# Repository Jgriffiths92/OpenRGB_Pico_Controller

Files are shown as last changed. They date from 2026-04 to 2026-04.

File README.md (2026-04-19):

# RGB Pico SATA Controller

This project is an open-source RGB controller designed to interface with 12v RGB devices using a Raspberry Pi Pico microcontroller. It features custom firmware and hardware, supporting the OpenRGB protocol for seamless integration with popular RGB control software.

RGB Pico SATA Controller is an open-source hardware and firmware project that enables control of standard (dumb) 12V RGB devices (such as common 12V RGB LED strips and PC lighting) using a Raspberry Pi Pico microcontroller. The controller connects via a SATA power connector for easy integration into PC builds and communicates with the OpenRGB desktop application using the OpenRGB protocol. This allows users to synchronize and customize their RGB lighting through a unified software interface.

The project includes:
- Custom PCB design (KiCad)
- Firmware written in C for the Raspberry Pi Pico
- Support for OpenRGB protocol for cross-platform compatibility

## Features
- Control standard (dumb) 12V RGB LEDs (common anode, 4-pin) via SATA power connector
- Seamless integration with OpenRGB software
- USB HID communication for low-latency control
- Open-source hardware (schematic, PCB, Gerber files)
- Easy-to-build firmware with CMake
- Designed for PC modding and custom lighting projects

## Folder Structure
- `Firmware/` — Source code for the Pico firmware (C, CMake)
- `Gerber/` — PCB manufacturing files for the controller
- `RGB_PICO_SATA_CONTROLLER.kicad_*` — KiCad schematic and PCB design files

## Hardware Overview
The hardware consists of a custom PCB designed in KiCad, featuring:
- Raspberry Pi Pico (RP2040) microcontroller
- SATA power input for 12V supply
- MOSFET drivers for switching 12V power to each RGB channel
- 4-pin connectors for standard 12V RGB LED strips (common anode)

All design files are provided in the repository (`.kicad_sch`, `.kicad_pcb`, and Gerber files).
## Getting Started
### Hardware
1. Open the KiCad project files (`RGB_PICO_SATA_CONTROLLER.kicad_sch`, `.kicad_pcb`) to view or modify the schematic and PCB layout.
2. Use the Gerber files in the `Gerber/` directory to order PCBs from your preferred manufacturer.
3. Assemble the board using the schematic and bill of materials (BOM).
4. Solder the Raspberry Pi Pico and connectors as indicated.

### Firmware
1. Install the Raspberry Pi Pico SDK and required toolchain (CMake, GCC, etc.).
2. Clone this repository and navigate to the `Firmware/` directory.
3. Build the firmware:
   ```sh
   mkdir build
   cd build
   cmake ..
   make
   ```
4. Connect your Pico in BOOTSEL mode and copy the generated `.uf2` file to the Pico's USB drive.

### Software (OpenRGB)
1. Download and install the OpenRGB application from [openrgb.org](https://openrgb.org/).
2. Connect the RGB Pico SATA Controller to your PC via USB.
3. Open OpenRGB and the controller should appear as a supported device.
4. Configure and control your RGB devices through the OpenRGB interface.

## OpenRGB Protocol
The firmware implements the OpenRGB protocol, allowing the controller to be recognized and managed by the OpenRGB desktop application. For protocol details, see `Firmware/openrgb_protocol.c` and `Firmware/openrgb_protocol.h`.

## License
## Contributing
Contributions are welcome! Please open issues or pull requests for bug fixes, new features, or suggestions.

## License
This project is licensed under the GNU General Public License v3.0 (GPLv3).

Copyright (C) [2026] [Your Name or Organization]

This program is free software: you can redistribute it and/or modify
it under the terms of the GNU General Public License as published by
the Free Software Foundation, either version 3 of the License, or
(at your option) any later version.

This program is distributed in the hope that it will be useful,
but WITHOUT ANY WARRANTY; without even the implied warranty of
MERCHANTABILITY or FITNESS FOR A PARTICULAR PURPOSE.  See the
GNU General Public License for more details.

You should have received a copy of the GNU General Public License
along with this program.  If not, see <https://www.gnu.org/licenses/>.

---
Feel free to contribute or open issues for suggestions and improvements.

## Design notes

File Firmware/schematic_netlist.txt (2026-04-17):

# Schematic Netlist for RGB_PICO_SATA_CONTROLLER (from PCB analysis)

# Pico Header (J2) Connections
J2.1  GP0
J2.2  GP1
J2.4  GP2
J2.5  GP3
J2.6  GP4
J2.7  GP5
J2.8  GP6
J2.9  GP7
J2.10 GP8
J2.11 GP9
J2.12 GP10
J2.13 GP11

# RGB Output Connectors
# J4, J5, J6, J7 are assumed to be RGB1, RGB2, RGB3, RGB4
# Each has pins for +12V_F, R, G, B

# Example for J7 (RGB4):
J7.1 +12V_F
J7.2 RGB4_R
J7.3 RGB4_G
J7.4 RGB4_B

# MOSFET Drivers (Q1-Q12, not all shown)
# Example for Q1 (RGB1_R):
Q1.1 GP0
Q1.2 GND
Q1.3 RGB1_R

# Net Assignments
net RGB1_R (connects: Q1.3, J4.2)
net RGB1_G (connects: Q2.3, J4.3)
net RGB1_B (connects: Q3.3, J4.4)
net RGB2_R (connects: Q4.3, J5.2)
net RGB2_G (connects: Q5.3, J5.3)
net RGB2_B (connects: Q6.3, J5.4)
net RGB3_R (connects: Q7.3, J6.2)
net RGB3_G (connects: Q8.3, J6.3)
net RGB3_B (connects: Q9.3, J6.4)
net RGB4_R (connects: Q10.3, J7.2)
net RGB4_G (connects: Q11.3, J7.3)
net RGB4_B (connects: Q12.3, J7.4)

# Power Nets
net +12V_F (connects: J4.1, J5.1, J6.1, J7.1, F1.2)
net GND (connects: all MOSFETs pad 2, Pico GND, D1.1, etc.)

# This netlist can be used as a reference to manually reconstruct the schematic in KiCad.

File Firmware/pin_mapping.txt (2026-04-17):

Pico GPIO to RGB Output Mapping (from PCB):

RGB1_R: GP0  (Pico GPIO0)
RGB1_G: GP1  (Pico GPIO1)
RGB1_B: GP2  (Pico GPIO2)
RGB2_R: GP3  (Pico GPIO3)
RGB2_G: GP4  (Pico GPIO4)
RGB2_B: GP5  (Pico GPIO5)
RGB3_R: GP6  (Pico GPIO6)
RGB3_G: GP7  (Pico GPIO7)
RGB3_B: GP8  (Pico GPIO8)
RGB4_R: GP9  (Pico GPIO9)
RGB4_G: GP10 (Pico GPIO10)
RGB4_B: GP11 (Pico GPIO11)

Firmware defines (for main.c):
#define RGB1_R 0
#define RGB1_G 1
#define RGB1_B 2
#define RGB2_R 3
#define RGB2_G 4
#define RGB2_B 5
#define RGB3_R 6
#define RGB3_G 7
#define RGB3_B 8
#define RGB4_R 9
#define RGB4_G 10
#define RGB4_B 11

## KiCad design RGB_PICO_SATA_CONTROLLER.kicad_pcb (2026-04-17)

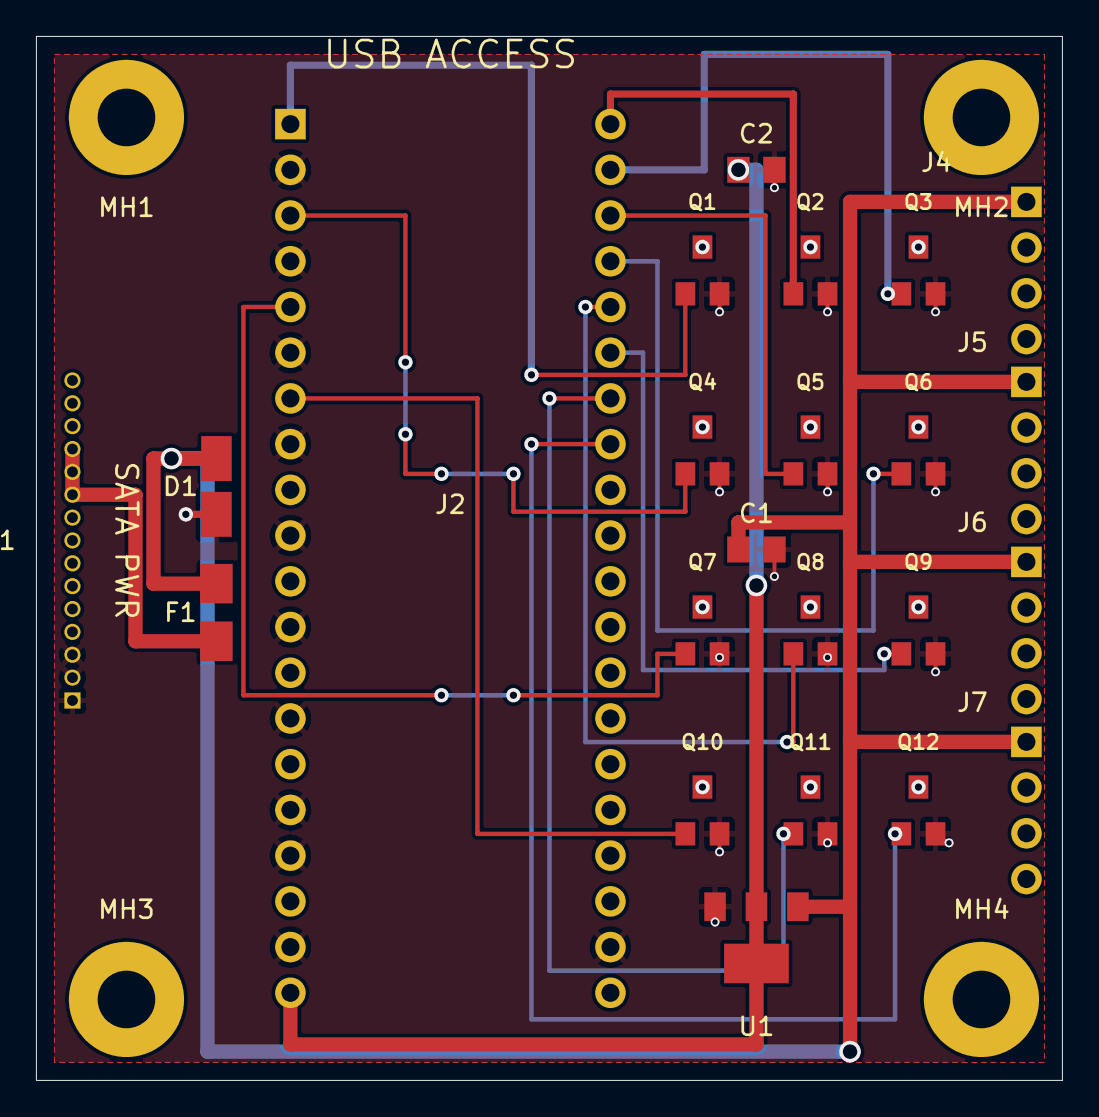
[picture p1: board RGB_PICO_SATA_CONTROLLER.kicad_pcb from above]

Board: 4 copper layers, 57.0 x 58.0 mm, 27 parts (0 on the bottom side), 28 nets.

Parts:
C1, C2: 10uF; C_0805_2012Metric
D1: 1.5KE12A; D_SMB
F1: 1A; Fuse_1206_3216Metric
J1: SATA_POWER; PinHeader_1x15_P2.54mm_Vertical
J2: PICO_HEADER; PinHeader_2x20_P2.54mm_Vertical
J4: RGB1; PinHeader_1x04_P2.54mm_Vertical
J5: RGB2; PinHeader_1x04_P2.54mm_Vertical
J6: RGB3; PinHeader_1x04_P2.54mm_Vertical
J7: RGB4; PinHeader_1x04_P2.54mm_Vertical
MH1, MH2, MH3, MH4: MountingHole_3.2mm_M3
Q1, Q2, Q3, Q4, Q5, Q6, Q7, Q8, Q9, Q10, Q11, Q12: NMOS; SOT-23
U1: AMS1117-5.0; SOT-223-3_TabPin2

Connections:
+5V: C2.1, J2.39, U1.2, U1.4
+12V: F1.1, J1.10, J1.11, J1.12
+12V_F: C1.1, D1.2, F1.2, J4.1, J5.1, J6.1, J7.1, U1.3
GND: C1.2, C2.2, D1.1, J1.1, J1.2, J1.3, J2.3, J2.7, J2.11, J2.15, J2.19, J2.23, J2.27, J2.31, J2.33, J2.37, J2.38, Q1.2, Q2.2, Q3.2, Q4.2, Q5.2, Q6.2, Q7.2, Q8.2, Q9.2, Q10.2, Q11.2, Q12.2, U1.1
GP0: J2.1, Q1.1
GP1: J2.2, Q2.1
GP2: J2.4, Q3.1
GP3: J2.5, Q4.1
GP4: J2.6, Q5.1
GP5: J2.8, Q6.1
GP6: J2.9, Q7.1
GP7: J2.10, Q8.1
GP8: J2.12, Q9.1
GP9: J2.13, Q10.1
GP10: J2.14, Q11.1
GP11: J2.16, Q12.1
RGB1_B: J4.4, Q3.3
RGB1_G: J4.3, Q2.3
RGB1_R: J4.2, Q1.3
RGB2_B: J5.4, Q6.3
RGB2_G: J5.3, Q5.3
RGB2_R: J5.2, Q4.3
RGB3_B: J6.4, Q9.3
RGB3_G: J6.3, Q8.3
RGB3_R: J6.2, Q7.3
RGB4_B: J7.4, Q12.3
RGB4_G: J7.3, Q11.3
RGB4_R: J7.2, Q10.3

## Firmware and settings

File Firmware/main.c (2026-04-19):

// Firmware for controlling standard (dumb) 12V RGB LED strips (common anode, 4-pin)
// Each color channel is controlled via PWM on a dedicated GPIO pin.
// Not for addressable LEDs (e.g., WS2812, SK6812).

#include "pico/stdlib.h"
#include "hardware/pwm.h"
#include "openrgb_protocol.h"


// Define GPIO pins for 4 RGB ports (change as needed for your board)
// Each port supports one standard 12V RGB LED strip (R, G, B channels)
#define RGB1_R 0
#define RGB1_G 1
#define RGB1_B 2
#define RGB2_R 3
#define RGB2_G 4
#define RGB2_B 5
#define RGB3_R 6
#define RGB3_G 7
#define RGB3_B 8
#define RGB4_R 9
#define RGB4_G 10
#define RGB4_B 11

void set_all_rgb(const uint8_t rgb[12]) {
    // Set PWM level for each color channel of each port
    // rgb[0..2]: Port 1 (R, G, B)
    // rgb[3..5]: Port 2 (R, G, B)
    // rgb[6..8]: Port 3 (R, G, B)
    // rgb[9..11]: Port 4 (R, G, B)
    pwm_set_gpio_level(RGB1_R, rgb[0] * 257);
    pwm_set_gpio_level(RGB1_G, rgb[1] * 257);
    pwm_set_gpio_level(RGB1_B, rgb[2] * 257);
    pwm_set_gpio_level(RGB2_R, rgb[3] * 257);
    pwm_set_gpio_level(RGB2_G, rgb[4] * 257);
    pwm_set_gpio_level(RGB2_B, rgb[5] * 257);
    pwm_set_gpio_level(RGB3_R, rgb[6] * 257);
    pwm_set_gpio_level(RGB3_G, rgb[7] * 257);
    pwm_set_gpio_level(RGB3_B, rgb[8] * 257);
    pwm_set_gpio_level(RGB4_R, rgb[9] * 257);
    pwm_set_gpio_level(RGB4_G, rgb[10] * 257);
    pwm_set_gpio_level(RGB4_B, rgb[11] * 257);
}

int main() {
    stdio_init_all();
    // Initialize PWM for all RGB pins (for dumb RGB strips)
    const uint RGB_PINS[12] = {
        RGB1_R, RGB1_G, RGB1_B,
        RGB2_R, RGB2_G, RGB2_B,
        RGB3_R, RGB3_G, RGB3_B,
        RGB4_R, RGB4_G, RGB4_B
    };
    for (int i = 0; i < 12; ++i) {
        gpio_set_function(RGB_PINS[i], GPIO_FUNC_PWM);
        uint slice = pwm_gpio_to_slice_num(RGB_PINS[i]);
        pwm_set_enabled(slice, true);
    }

    openrgb_init(set_all_rgb);
    while (1) {
        openrgb_task();
    }
    return 0;
}

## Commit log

2026-04-17 Initial commit: KiCad RGB SATA controller project
    [RGB_PICO_SATA_CONTROLLER.kicad_pcb, RGB_PICO_SATA_CONTROLLER.kicad_sch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]
2026-04-17 Refactor code structure for improved readability and maintainability
    [RGB_PICO_SATA_CONTROLLER.kicad_pcb]
2026-04-17 Add temporary lock file for PCB to .gitignore
2026-04-19 Refactor RGB pin definitions and enhance firmware documentation in README.md
2026-04-19 Add CMake and VSCode configuration files for Raspberry Pi Pico support
